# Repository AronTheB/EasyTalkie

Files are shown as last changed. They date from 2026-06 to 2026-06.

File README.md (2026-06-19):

EasyTalkie

# A ESP32/ESPNOW based walkie talkie

## Description

This is a easy to build/use Walkie-Talkie, that work via the ESPNOW system. The project uses a ESP-32 S3, INMP441, MAX98357A, SSD1306 OLED SCREEN, and 1000mAH LIPO BATTERY.

Made for [fallout.hackclub.com](https://fallout.hackclub.com/)

### WHY I MADE THIS:

I made this project, beaceuse my mom always have to yell at me to hear that she is calling me. So i made this walkie talkie so we can communicate easier in the house. I think also anyone could use this for easy communication and also at event like fallout where there are hunderds of kids, and you need to quickly communicate something to your partner.

### HOW TO BUILD:

You can replicate this project at home pretty easily. Clone this repo and download all the neccesary files such as the gerber.zip for pcb .stp files for the 3d models to print and also use the BOM to find all the parts needed for the project. After everything arrives solder it like in the schematic. (The battery has to be manually wired as shown in the schematic, the gnd of the battery should be connected to the gnd pin on the xiao via wires), put the pcb in the case, it should fit like a glove. connect it to a computer via a cable and flash the ESP32 with the firmware and after a reboot it should start working.

### HOW TO USE/FEATURES:

After turning on the ESP-32's will find eachother if near and than use the button to trasmit audio between the walkie-talkies. the main feature is the communication, if u press the button you start speaking while holding the button down, it will start transmitting audio and if you are not holding the key down, you can receive audio.

## KiCad

### Schematic



### PCB



## Fusion 360



## Preview

https://github.com/user-attachments/assets/4c29f206-930c-4e9f-b8dc-11138d7f1e36

## BOM
make this into a mk table

| NAME | LINK | PRICE | QUANTITY | Need To Buy? |
|---|---|---|---|---|
| XIAO ESP32 S3 | [AliExpress](https://www.aliexpress.com/item/1005005382287176.html) | $6.64 | 2 | Yes |
| INMP441 | [AliExpress](https://www.aliexpress.com/item/1005007987577953.html) | $1.39 | 2 | Yes |
| MAX98357A | [AliExpress](https://www.aliexpress.com/item/1005007003802663.html) | $1.63 | 2 | Yes |
| SSD1306 | [AliExpress](https://www.aliexpress.com/item/32896971385.html) | $1.85 | 2 | Yes |
| LiPo 1000mAh | [AliExpress](https://www.aliexpress.com/item/1005004375261361.html) | $7.69 | 2 | Yes |
| SS-12D00 6mm | [AliExpress](https://www.aliexpress.com/item/1005005633418066.html) | $1.77 | 2 | Yes |
| 8Ω 1W 28mm Speaker | [AliExpress](https://www.aliexpress.com/item/1005005458778825.html) | $0.42 | 2 | Yes |
| MX Switches | [AliExpress](https://www.aliexpress.com/item/1005004285423123.html) | $2.86 | 1 | Yes |
| Keycaps | [AliExpress](https://www.aliexpress.com/item/1005009364428646.html) | $3.54 | 1 | Yes |
| PCB | JLCPCB | $2.00 | 1 | Yes |
| 3D Print | JLC3DP | $6.33 | 1 | Yes |
| **TOTAL** | | **$57.51** | | |

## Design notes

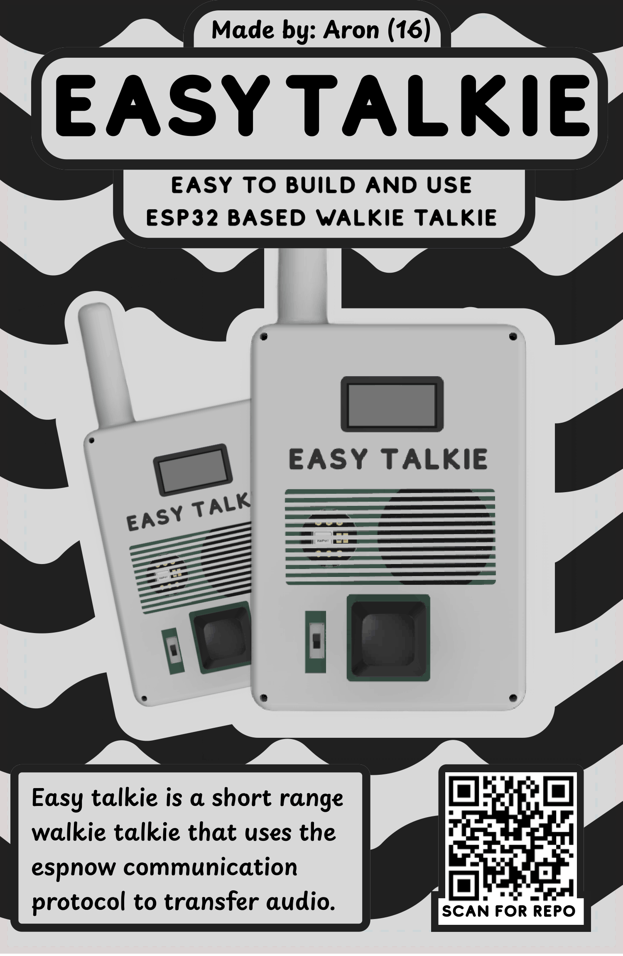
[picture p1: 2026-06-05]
Zine/EasyTalkie.png

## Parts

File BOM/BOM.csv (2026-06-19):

NAME | LINK | PRICE | QUANTITY | Need To buy?
XIAO ESP32 S3 | https://www.aliexpress.com/item/1005005382287176.html | $6,64 | 2 | Yes
INMP441 | https://www.aliexpress.com/item/1005007987577953.html | $1,39 | 2 | Yes
MAX98357A | https://www.aliexpress.com/item/1005007003802663.html | $1,63 | 2 | Yes
SSD1306 | https://www.aliexpress.com/item/32896971385.html | $1,85 | 2 | Yes
LiPo 1000mAh | https://www.aliexpress.com/item/1005004375261361.html | $7,69 | 2 | Yes
SS-12D00 6mm | https://www.aliexpress.com/item/1005005633418066.html | $1,77 | 2 | Yes
8Ω 1W 28mm Speaker | https://www.aliexpress.com/item/1005005458778825.html | $0,42 | 2 | Yes
Mx Switches | https://www.aliexpress.com/item/1005004285423123.html | $2,86 | 1 | Yes
Keycaps | https://www.aliexpress.com/item/1005009364428646.html | $3,54 | 1 | Yes
PCB | JLCPCP | $2 |  | Yes
3d print | JLC3DP | $6,33 |  | Yes
TOTAL: |  | $57.51

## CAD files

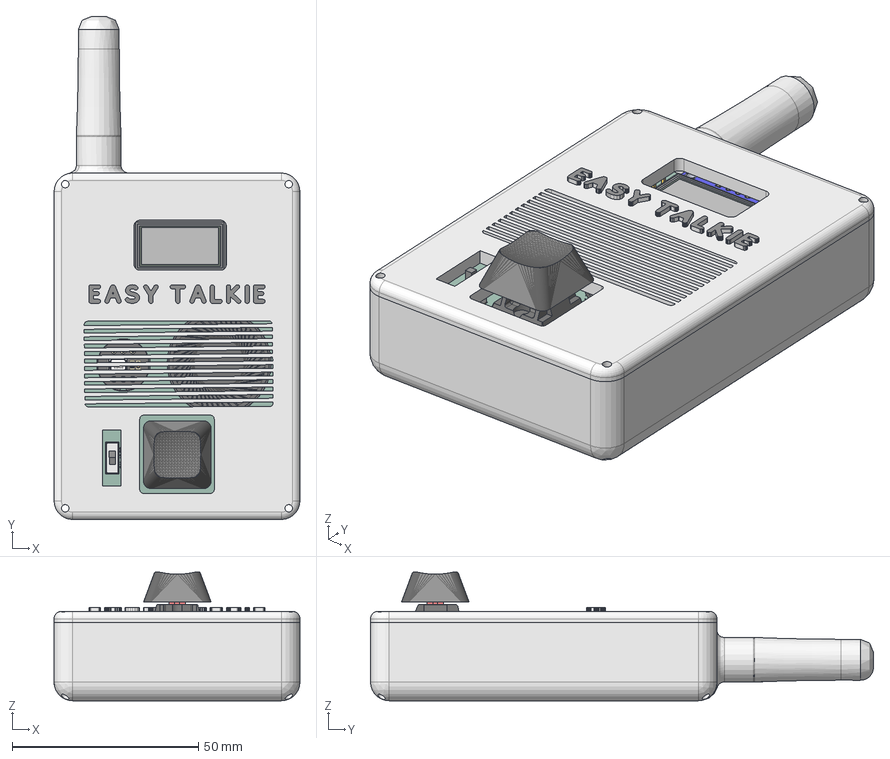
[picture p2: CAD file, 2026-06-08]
CAD/EasyTalkie.step
66.0 x 135.0 x 34.5 mm

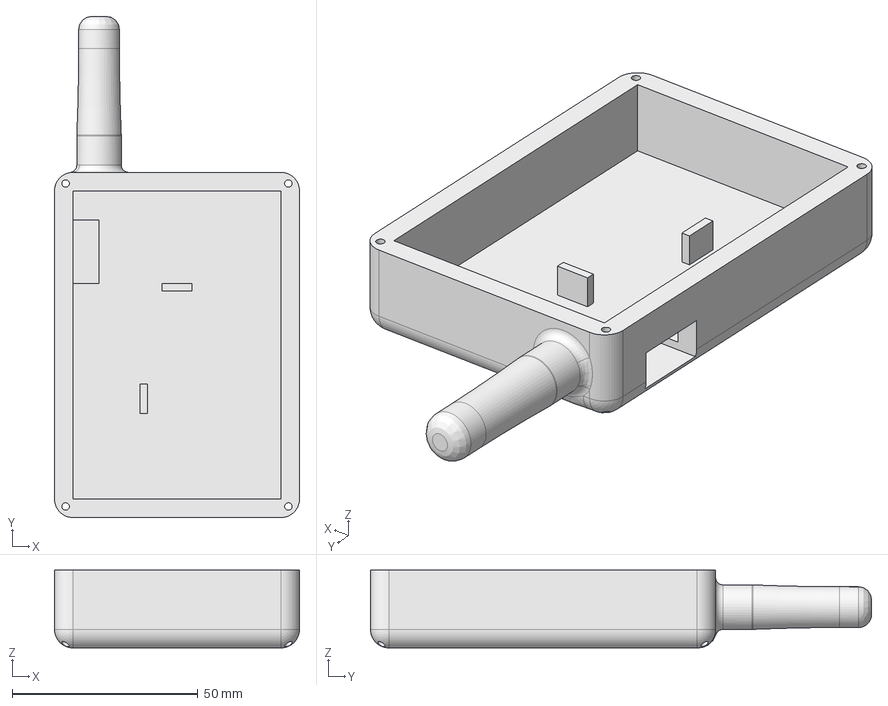
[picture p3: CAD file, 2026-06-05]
CAD/EasyTalkie-Bottom.step
66.0 x 135.0 x 21.0 mm

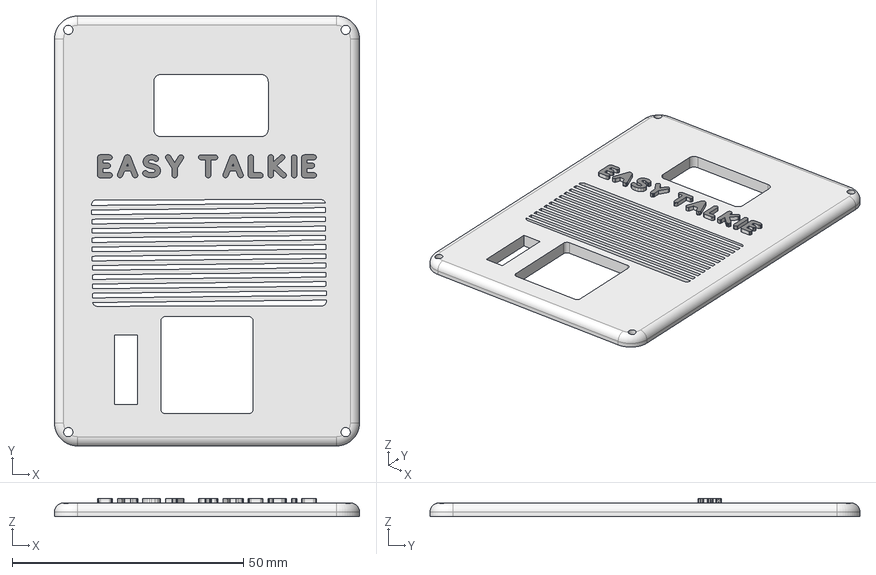
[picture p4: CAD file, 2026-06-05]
CAD/EasyTalkie-Top.step
66.0 x 93.0 x 4.00 mm

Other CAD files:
CAD/EasyTalkie.f3z

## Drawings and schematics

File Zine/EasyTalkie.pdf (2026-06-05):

# EASyTALKIE

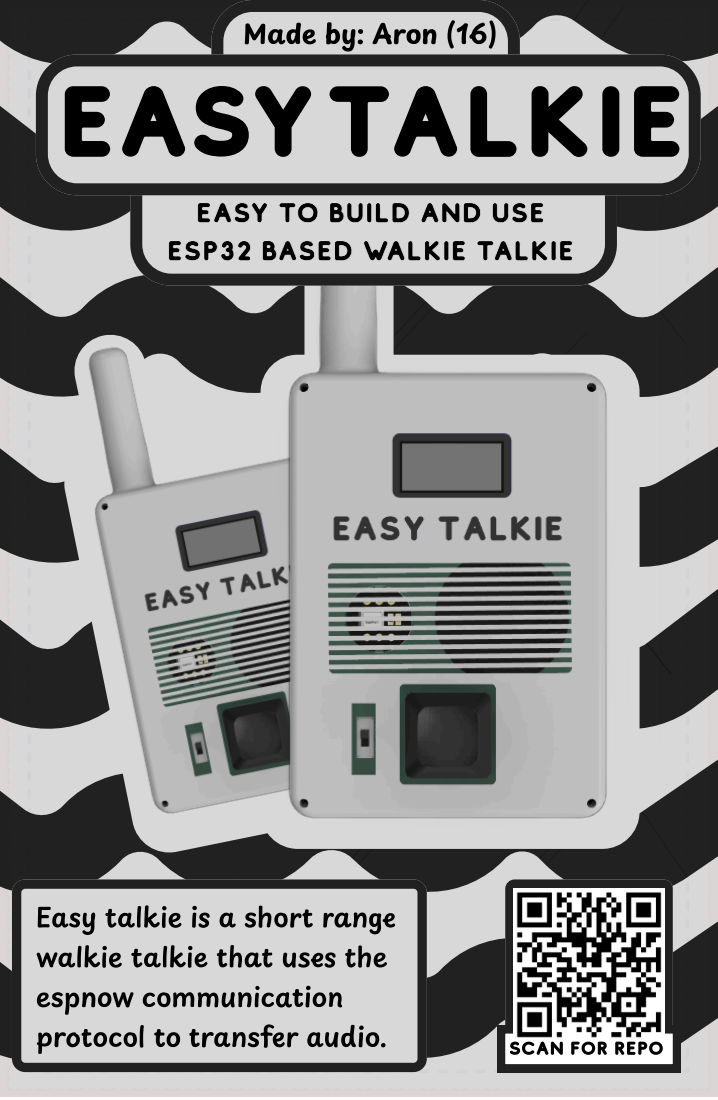
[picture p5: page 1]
protocol to transfer audio.; SCAN FOR REPO

Made by: Aron (16)

Easy talkie is a short range
walkie talkie that uses the
espnow communication

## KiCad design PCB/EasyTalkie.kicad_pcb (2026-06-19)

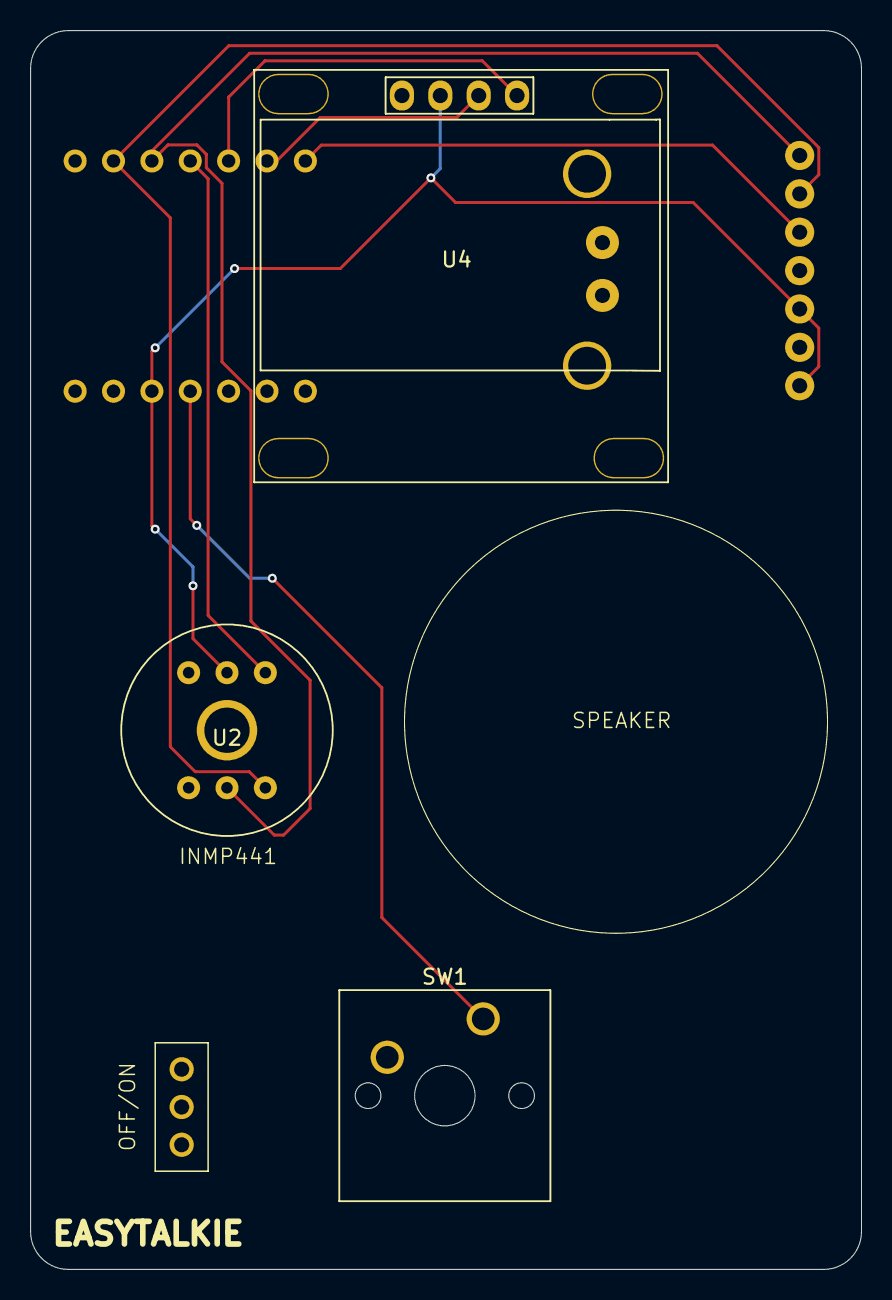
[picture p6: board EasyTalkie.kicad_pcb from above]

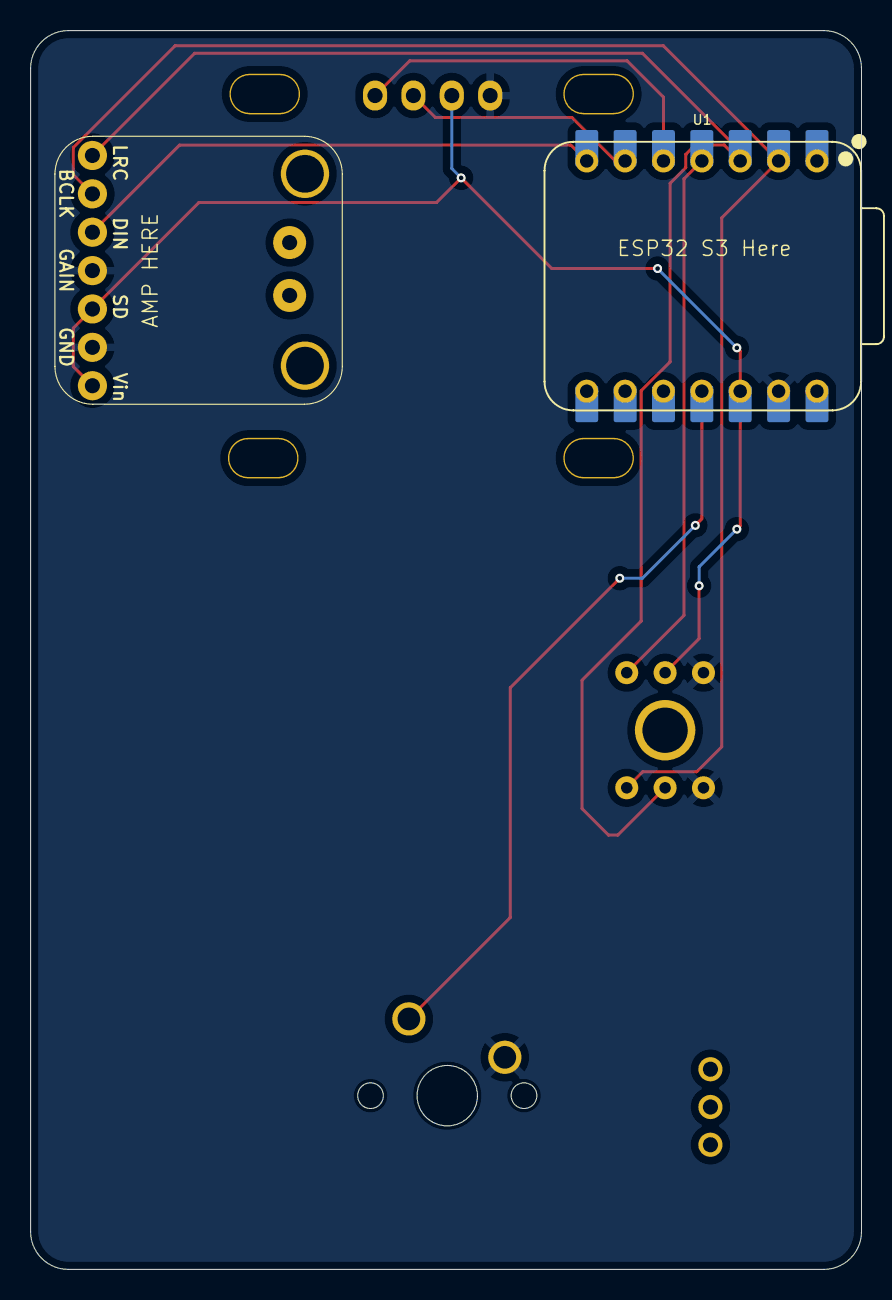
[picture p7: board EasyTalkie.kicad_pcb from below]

Board: 2 copper layers, 55.0 x 82.0 mm, 6 parts (2 on the bottom side), 9 nets.

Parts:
SW1: SW_Push; SW_Cherry_MX_1.00u_PCB
SW2: SS12D00
U1: XIAO-ESP32-S3-DIP
U2: INMP441; inmp441
U3: MAX98357A; MAX98357A Module
U4: SSD1306; 128x64OLED

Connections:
3V: U1.12 (3V3), U2.2 (VDD), U3.4 (~SD_MODE), U3.7 (VDD), U4.2 (VCC)
GND: SW1.2, U1.13 (GND), U2.1 (GND), U2.4 (L/R), U3.2 (GAIN_SLOT), U3.3 (GND), U4.1 (GND)
GPI02: U1.2 (GPIO2_A1_D1), U2.6 (SCK), U3.16 (BCLK)
GPI03: U1.3 (GPIO3_A2_D2), U2.5 (WS), U3.14 (LRCLK)
GPI04: U1.4 (GPIO4_A3_D3), U2.3 (SD)
GPI05: U1.5 (GPIO5_A4_D4_SDA), U4.4 (SDA)
GPI06: U1.6 (GPIO6_A5_D5_SCL), U4.3 (SCL)
GPI043: U1.7 (GPIO43_D6_TX), U3.1 (DIN)
unnamed: SW1.1, U1.11 (GPIO9_A10_D10_MOSI)

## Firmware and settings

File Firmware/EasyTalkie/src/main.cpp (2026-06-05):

// Todo - Add oled screen and also the connect to wifi


#include <Arduino.h>
#include <WiFi.h>
#include <esp_now.h>
#include <esp_wifi.h>
#include <driver/i2s.h>

#define SAMPLE_RATE 16000
#define SAMPLE_PER_CHUNK 128
#define ESP_NOW_CHANNEL 1

#define MIC_SCK GPIO_NUM_2
#define MIC_WS GPIO_NUM_3
#define MIC_SD GPIO_NUM_4

#define SPK_DIN GPIO_NUM_43
#define SPK_LR GPIO_NUM_3
#define SPK_BCLK GPIO_NUM_2

#define BTN_PIN GPIO_NUM_9


// Buffer for audio samples, basicly the rx_head and rx_tail show where the write and read is happening.
#define BUF_SAMPLES (300 * 16)

static int16_t rx_buf[BUF_SAMPLES];
static volatile int rx_head = 0, rx_tail = 0;

static void buf_push(const int16_t * src, int n) {
  for (int i = 0; i < n; i++) {
    rx_buf[rx_head] = src[i];
    rx_head = (rx_head + 1) % BUF_SAMPLES;
  }
}
static void buf_pop(int16_t * dst, int n) {
  for (int i = 0; i < n; i++) {
    dst[i] = (rx_head != rx_tail) ? rx_buf[rx_tail] : 0;
    if (rx_head != rx_tail) rx_tail = (rx_tail + 1) % BUF_SAMPLES;
  }
}
static void buf_flush() {
  rx_head = rx_tail = 0;
}

// basic ESPNOW Setup.

static uint8_t BROADCAST[] = {
  0xFF,
  0xFF,
  0xFF,
  0xFF,
  0xFF,
  0xFF
};

static void on_recv(const uint8_t * ,
  const uint8_t * data, int len) {
  buf_push((const int16_t * ) data, len / 2);
}

#define PKT_SAMPLES 125
static int16_t pkt[PKT_SAMPLES];
static int pkt_pos = 0;

static void send_sample(int16_t s) {
  pkt[pkt_pos++] = s;
  if (pkt_pos == PKT_SAMPLES) {
    esp_now_send(BROADCAST, (uint8_t * ) pkt, sizeof(pkt));
    pkt_pos = 0;
  }
}
static void send_flush() {
  if (pkt_pos) {
    esp_now_send(BROADCAST, (uint8_t * ) pkt, pkt_pos * 2);
    pkt_pos = 0;
  }
}

static void espnow_setup() {
  WiFi.mode(WIFI_STA);
  WiFi.disconnect();
  esp_wifi_set_channel(ESP_NOW_CHANNEL, WIFI_SECOND_CHAN_NONE);

  if (esp_now_init() != ESP_OK) {
    Serial.println("Error initializing ESP-NOW");
    return;
  }
  esp_now_register_recv_cb(on_recv);
  esp_now_peer_info_t peerInfo = {};
  memcpy(peerInfo.peer_addr, BROADCAST, 6);
  peerInfo.channel = ESP_NOW_CHANNEL;
  peerInfo.encrypt = false;
  esp_now_add_peer(&peerInfo);
}

// Mic

enum Mode { MODE_NONE, MODE_MIC, MODE_SPK };
static Mode current_mode = MODE_NONE;
 
static void i2s_teardown() {
  if (current_mode != MODE_NONE) {
    i2s_driver_uninstall(I2S_NUM_0);
    current_mode = MODE_NONE;
  }
}

static void mic_mode() {
  if (current_mode == MODE_MIC) return;
  i2s_teardown();
 
  i2s_config_t cfg = {
    .mode = (i2s_mode_t)(I2S_MODE_MASTER | I2S_MODE_RX),
    .sample_rate = SAMPLE_RATE,
    .bits_per_sample = I2S_BITS_PER_SAMPLE_32BIT,
    .channel_format = I2S_CHANNEL_FMT_ONLY_LEFT,   // L/R tied GND = left
    .communication_format = I2S_COMM_FORMAT_STAND_I2S,
    .intr_alloc_flags = ESP_INTR_FLAG_LEVEL1,
    .dma_buf_count = 4,
    .dma_buf_len = 64,
    .use_apll = false,
    .tx_desc_auto_clear = false,
  };
  i2s_pin_config_t pins = {
    .bck_io_num = MIC_SCK,
    .ws_io_num = MIC_WS,
    .data_out_num = I2S_PIN_NO_CHANGE,
    .data_in_num = MIC_SD,
  };
  i2s_driver_install(I2S_NUM_0, &cfg, 0, NULL);
  i2s_set_pin(I2S_NUM_0, &pins);
  current_mode = MODE_MIC;
}

// Speaker

static void spk_mode() {
  if (current_mode == MODE_SPK) return;
  i2s_teardown();

  i2s_config_t cfg = {
    .mode = (i2s_mode_t)(I2S_MODE_MASTER | I2S_MODE_TX),
    .sample_rate = SAMPLE_RATE,
    .bits_per_sample = I2S_BITS_PER_SAMPLE_32BIT,
    .channel_format = I2S_CHANNEL_FMT_ONLY_LEFT,
    .communication_format = I2S_COMM_FORMAT_STAND_I2S,
    .intr_alloc_flags = ESP_INTR_FLAG_LEVEL1,
    .dma_buf_count = 4,
    .dma_buf_len = 64,
    .use_apll = false,
    .tx_desc_auto_clear = false,
  };

  i2s_pin_config_t pins = {
    .bck_io_num = SPK_BCLK,
    .ws_io_num = SPK_LR,
    .data_out_num = SPK_DIN,
    .data_in_num = I2S_PIN_NO_CHANGE,
  };
  i2s_driver_install(I2S_NUM_0, &cfg, 0, NULL);
  i2s_set_pin(I2S_NUM_0, &pins);
  current_mode = MODE_SPK;
}

static void mic_task() {
  int32_t raw[SAMPLE_PER_CHUNK];
  size_t br = 0;
  i2s_read(I2S_NUM_0, raw, sizeof(raw), &br, portMAX_DELAY);
  int n = br /4;
  for (int i = 0; i < n; i++) {
    int32_t s = raw[i] >> 16;
    send_sample((int16_t) s);
  }
}

static void spk_task() {
  int16_t chunk[SAMPLE_PER_CHUNK];
  int16_t stereo[SAMPLE_PER_CHUNK * 2];
  buf_pop(chunk, SAMPLE_PER_CHUNK);
  for (int i = 0; i < SAMPLE_PER_CHUNK; i++) {
    stereo[i * 2] = chunk[i];
    stereo[i * 2 + 1] = chunk[i];
  }
  size_t bw = 0;
  i2s_write(I2S_NUM_0, stereo, sizeof(stereo), &bw, portMAX_DELAY);
}

// Main

void setup() {
  Serial.begin(115200);

  pinMode(BTN_PIN, INPUT_PULLUP);
  espnow_setup();
}

void loop() {
  static bool was_talking = false;
  bool talking = (digitalRead(BTN_PIN) == LOW);
  if (talking && !was_talking) {
    mic_mode();
  } else if (!talking && was_talking) {
    send_flush();
    buf_flush();
    spk_mode();
  }    
  was_talking = talking;

  if (talking) {
    mic_task();
  } else {
    spk_task();
  }
}

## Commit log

2026-05-23 Enhance README with project details and images
    Added a project description and images for schematic, PCB, and Fusion 360.
2026-06-05 Add BOM section with component details to README
    Added a Bill of Materials (BOM) section with details on components, links, prices, and quantities.
2026-06-05 Update README with project replication instructions
    Added instructions for replicating the project at home, including cloning the repo, downloading necessary files, and flashing the ESP32.
2026-06-09 Improve build instructions in README.md
    Updated instructions for building the project to include fitting the PCB in the case and connecting it to a computer for flashing.
2026-06-19 Update README with detailed battery wiring instructions
    Clarified battery wiring instructions in the build section of the README.
